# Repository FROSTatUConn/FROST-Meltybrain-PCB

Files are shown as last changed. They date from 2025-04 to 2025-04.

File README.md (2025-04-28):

# FROST-Meltybrain-PCB
Repository for all of the PCB design files in KiCAD for the FROST meltybrain

## COMPONENTS
- H3LIS331DL Sparkfun breakout board
- Arduino Nano microcontroller
- WS2812B RGB LEDs

## Version 2.0
**TODO:**
- **ACCELEROMETER PINS ARE FLIPPED HORIZONTALLY**
- Accelerometer insufficient spacing (too tight, increase spacing)
- Arduino pin staggering still too loose, shift pins over slightly

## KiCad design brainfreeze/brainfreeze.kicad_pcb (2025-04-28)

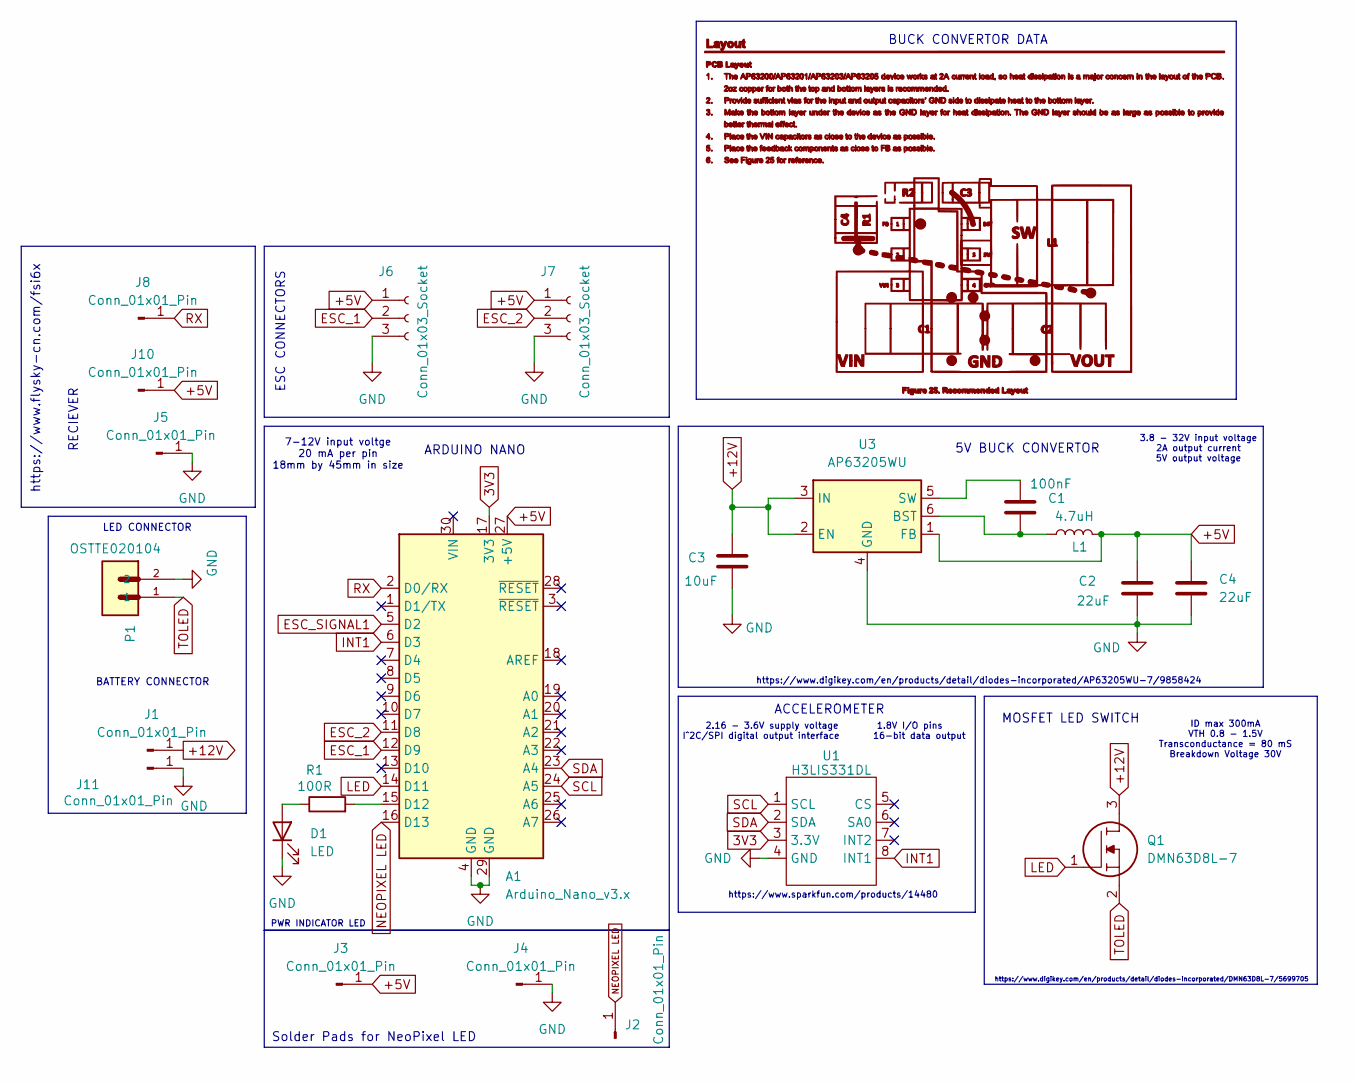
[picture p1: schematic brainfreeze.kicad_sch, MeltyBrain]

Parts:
A1: Arduino_Nano_v3.x; NANO_FIT
C1: 100nF; C_0402_1005Metric
C2, C4: 22uF; C_1206_3216Metric
C3: 10uF; C_0805_2012Metric
D1: LED; LED_0603_1608Metric
J1, J3, J4, J5, J10, J11: Conn_01x01_Pin; SolderWire-1sqmm_1x01_D1.4mm_OD2.7mm
J2, J8: Conn_01x01_Pin; SolderWire-0.5sqmm_1x01_D0.9mm_OD2.1mm
J6, J7: Conn_01x03_Socket; ESC CON
L1: 4.7uH; L_1210_3225Metric
P1: OSTTE020104; OST_OSTTE020104
Q1: DMN63D8L-7; MOSFET; Mouser Part Number 621-DMN63D8L-7
R1: 100R; R_0603_1608Metric
U1: H3LIS331DL; Accelerometer
U3: AP63205WU; TSOT-23-6

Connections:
3V3: A1.17 (3V3), U1.3 (3.3V)
+5V: A1.27 (+5V), C2.1, C4.1, J3.1, J6.1, J7.1, J10.1, L1.2, U3.1 (FB)
+12V: C3.1, J1.1, Q1.3, U3.2 (EN), U3.3 (IN)
ESC_1: A1.12 (D9), J6.2
ESC_2: A1.11 (D8), J7.2
ESC_SIGNAL1: A1.5 (D2)
ESC_SIGNAL2: A1.21 (A2)
ESC_SIGNAL3: A1.22 (A3)
GND: A1.4 (GND), A1.29 (GND), C2.2, C3.2, C4.2, D1.1 (K), J4.1, J5.1, J6.3, J7.3, J11.1, P1.2, U1.4 (GND), U3.4 (GND)
INT1: A1.6 (D3), U1.8 (INT1)
LED: A1.14 (D11), Q1.1
NEOPIXEL LED: A1.16 (D13), J2.1
unnamed: A1.15 (D12), R1.2
unnamed: D1.2 (A), R1.1
unnamed: C1.1, L1.1, U3.6 (BST)
unnamed: C1.2, U3.5 (SW)
RX: A1.2 (D0/RX), J8.1
SCL: A1.24 (A5), U1.1 (SCL)
SDA: A1.23 (A4), U1.2 (SDA)
TOLED: P1.1, Q1.2

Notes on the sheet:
LED CONNECTOR
ESC CONNECTORS
BUCK CONVERTOR DATA
ACCELEROMETER
RECIEVER
ID max 300mA VTH 0.8 - 1.5V Transconductance = 80 mS Breakdown Voltage 30V
MOSFET LED SWITCH
https://www.digikey.com/en/products/detail/diodes-incorporated/AP63205WU-7/9858424
https://www.flysky-cn.com/fsi6x
3.8 - 32V input voltage 2A output current 5V output voltage
Solder Pads for NeoPixel LED
PWR INDICATOR LED
7-12V input voltge 20 mA per pin 18mm by 45mm in size
https://www.sparkfun.com/products/14480
BATTERY CONNECTOR
5V BUCK CONVERTOR
ARDUINO NANO
https://www.digikey.com/en/products/detail/diodes-incorporated/DMN63D8L-7/5699705
2.16 - 3.6V supply voltage 1.8V I/O pins I^2C/SPI digital output interface 16-bit data output

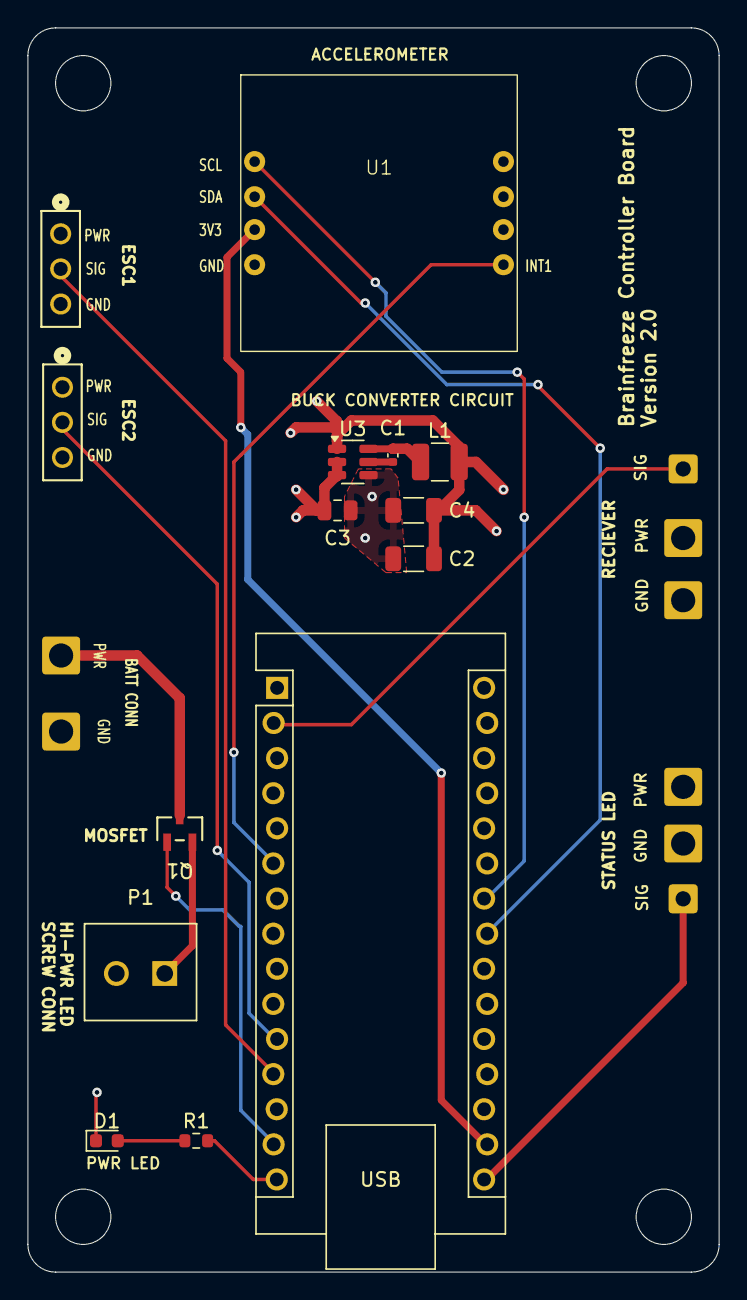
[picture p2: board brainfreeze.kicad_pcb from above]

Board: 4 copper layers, 50.0 x 90.0 mm, 22 parts (0 on the bottom side), 17 nets.

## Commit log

2025-02-17 Add files via upload
    Schematic, PCB, and footprints for MeltyBrain robot
    [MOSFET.kicad_sch, accelerometer.kicad_sch, brainfreeze.kicad_pcb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]
2025-02-18 updated with screwholes
    [MOSFET.kicad_sch, accelerometer.kicad_sch, brainfreeze.kicad_pcb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]
2025-03-31 Add files via upload
    Final PCB design
    [brainfreeze.kicad_pcb]
2025-03-31 Final PCB Design
    [brainfreeze.kicad_pcb]
2025-04-08 Updated PCB
    [MOSFET.kicad_sch, accelerometer.kicad_sch, brainfreeze.kicad_pcb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]
2025-04-15 Created gerber files
    [brainfreeze-B_Mask.gbs, brainfreeze-B_Paste.gbp, brainfreeze-B_Silkscreen.gbo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]
2025-04-15 Gerber files
2025-04-15 added .gitignore for *.zip, fillet + dimensioned PCB
    [brainfreeze.kicad_pcb]
2025-04-15 Added version number to board
    [brainfreeze.kicad_pcb]
